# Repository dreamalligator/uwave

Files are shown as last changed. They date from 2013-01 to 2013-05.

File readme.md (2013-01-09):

uwave
#uWave Theremin
One of three devices made for EECS Senior Design at UCF, Fall 2012. See http://www.eecs.ucf.edu/seniordesign/su2012fa2012/g01.

##Related 

* [SenseBox](https://github.com/antivapor/sensebox)
* [Expandome](https://github.com/antivapor/expandome)
* [EMI-Browser](https://github.com/antivapor/emi-browser)

##License
This work is licensed under a [Creative Commons Attribution-ShareAlike 3.0 Unported License](http://creativecommons.org/licenses/by-sa/3.0/).

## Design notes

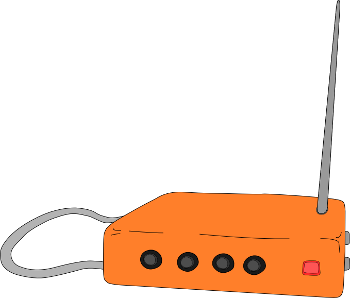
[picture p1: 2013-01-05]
uwave.png

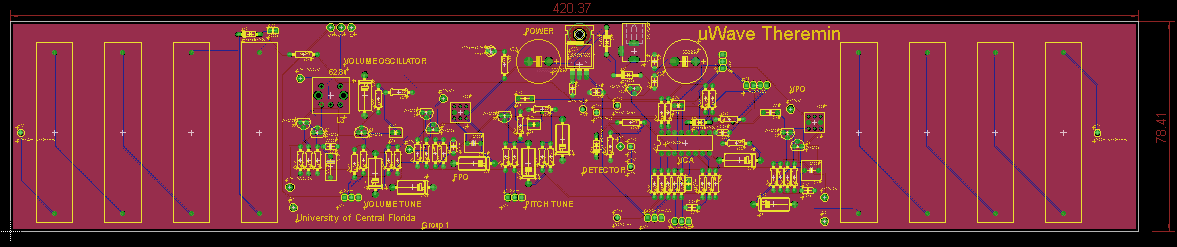
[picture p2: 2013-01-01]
pcb.png

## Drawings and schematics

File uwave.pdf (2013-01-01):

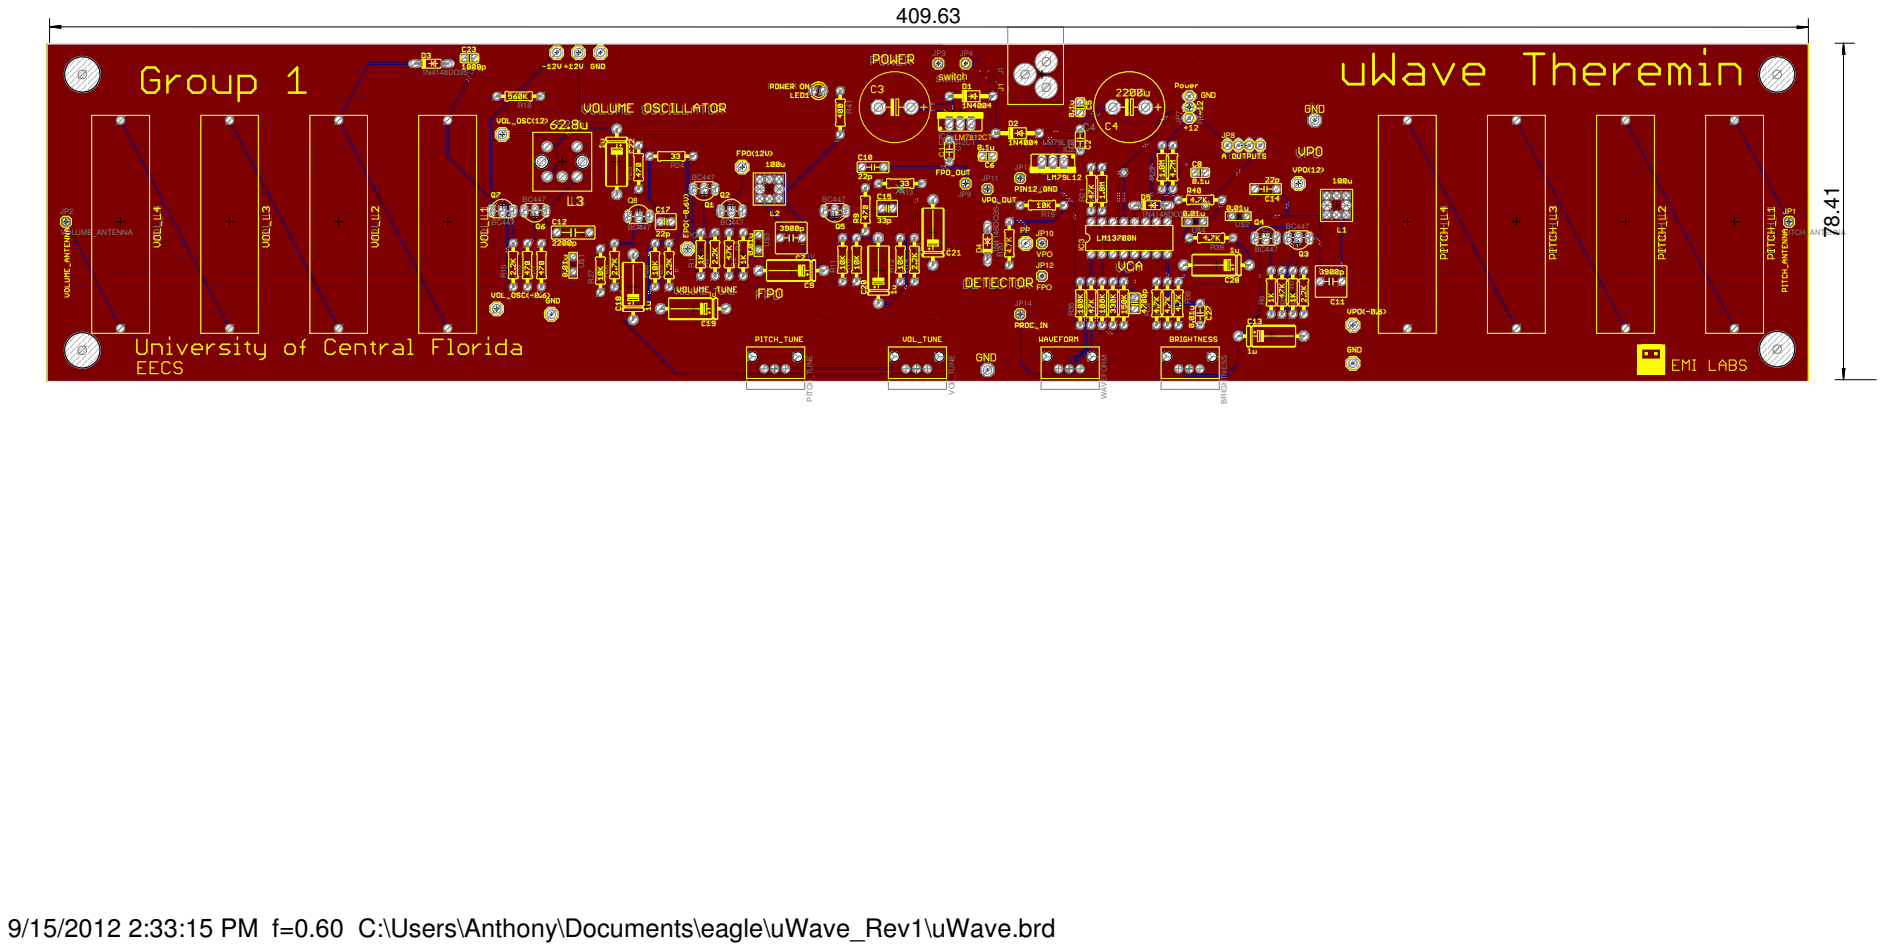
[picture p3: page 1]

9/15/2012 2:33:15 PM f=0.60 C:\Users\Anthony\Documents\eagle\uWave_Rev1\uWave.brd

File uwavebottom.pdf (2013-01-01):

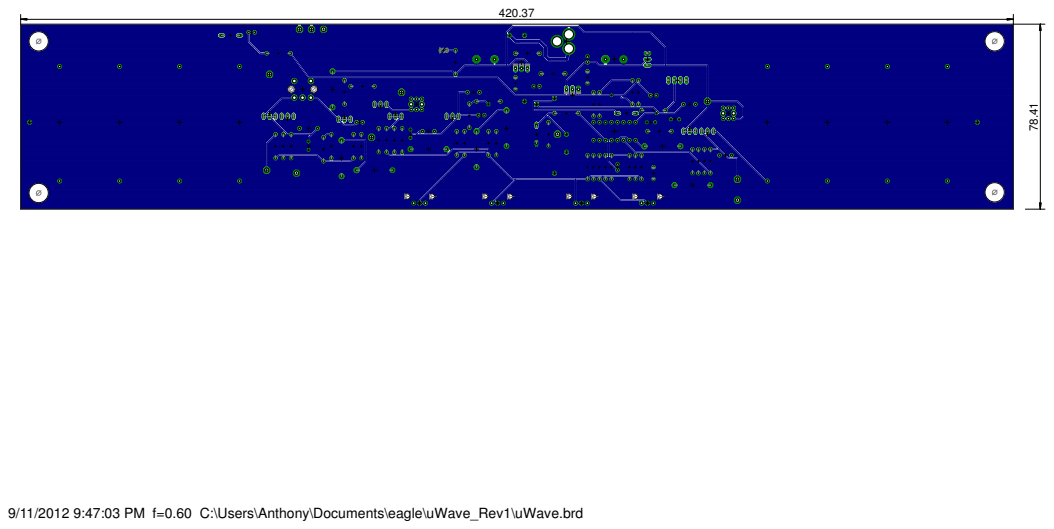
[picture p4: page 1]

9/11/2012 9:47:03 PM f=0.60 C:\Users\Anthony\Documents\eagle\uWave_Rev1\uWave.brd

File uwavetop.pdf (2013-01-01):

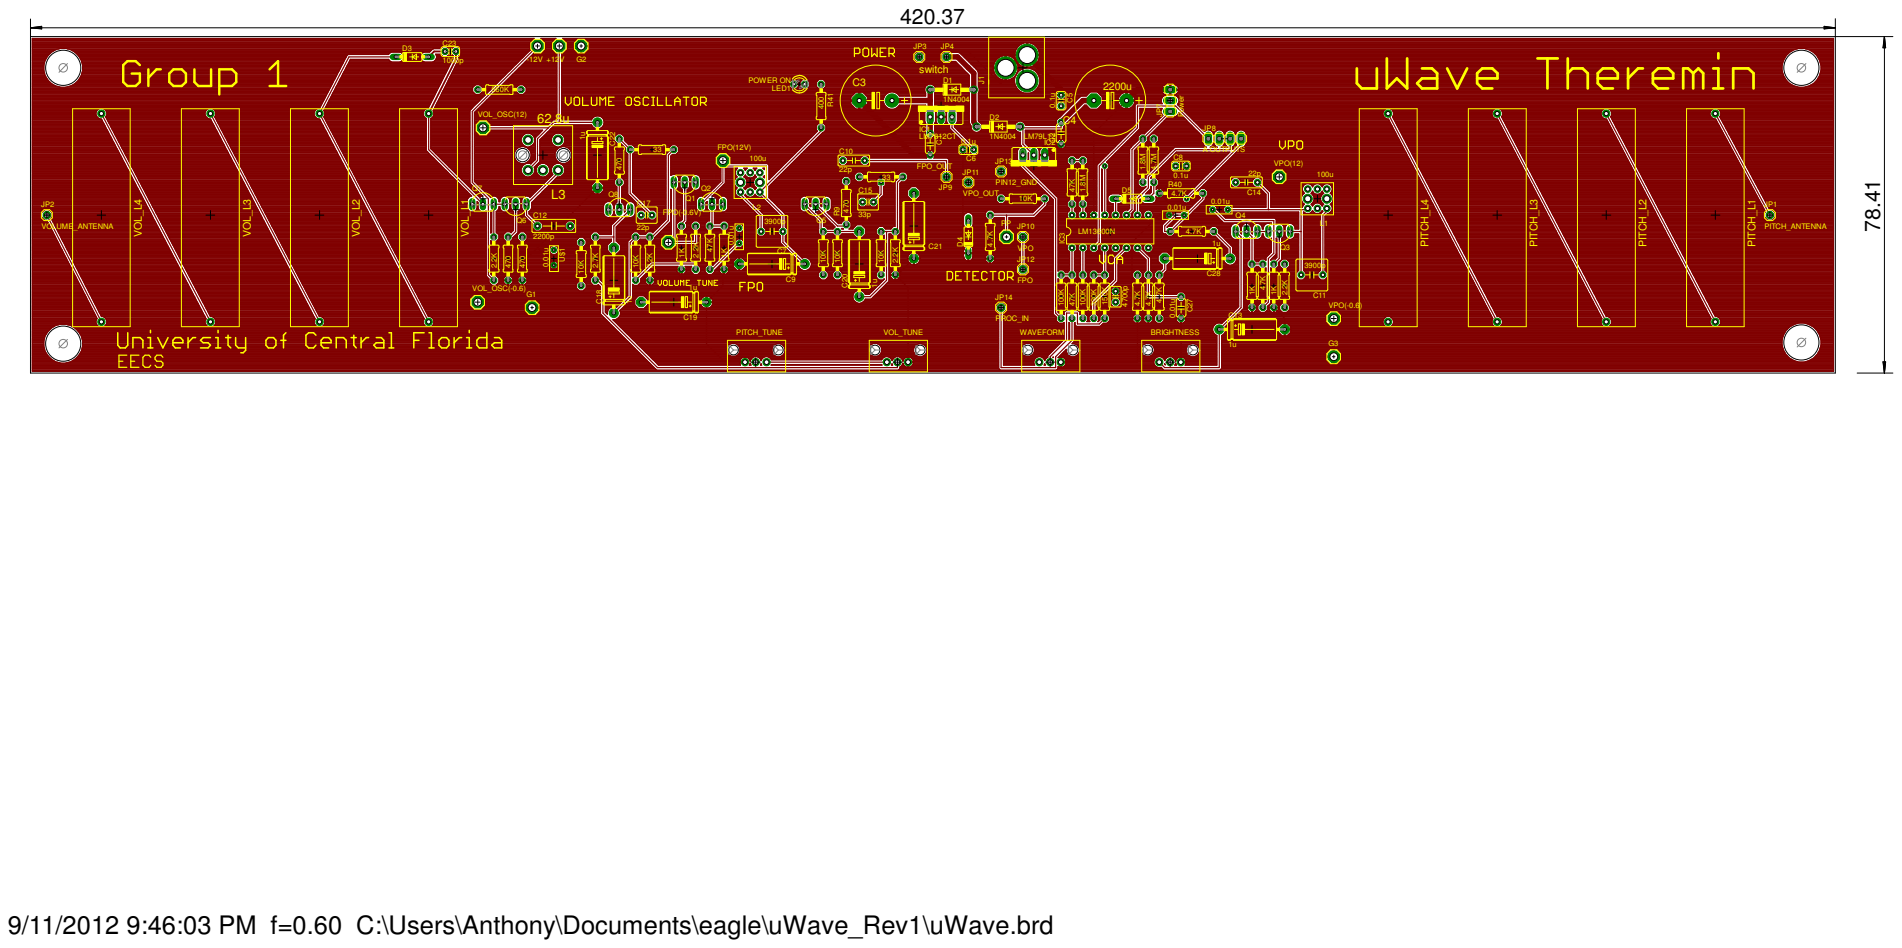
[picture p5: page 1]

9/11/2012 9:46:03 PM f=0.60 C:\Users\Anthony\Documents\eagle\uWave_Rev1\uWave.brd

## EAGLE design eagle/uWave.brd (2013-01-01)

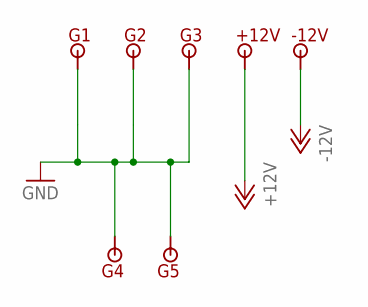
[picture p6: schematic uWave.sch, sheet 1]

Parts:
+12V: TEST1X1; TP1X1
-12V: TEST1X1; TP1X1
G1, G2, G3, G4, G5: TEST1X1; TP1X1

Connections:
+12V: +12V.P$1; also elsewhere on the board
-12V: -12V.P$1; also elsewhere on the board
GND: G1.P$1, G2.P$1, G3.P$1, G4.P$1, G5.P$1; also elsewhere on the board

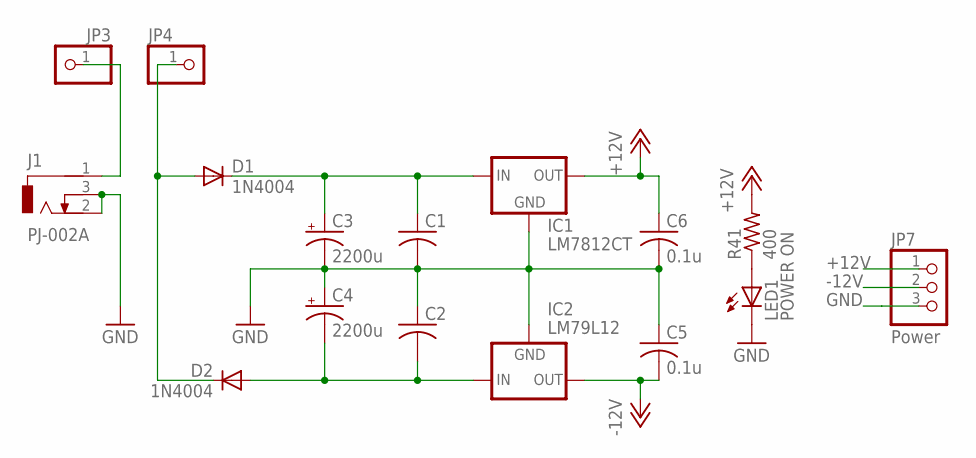
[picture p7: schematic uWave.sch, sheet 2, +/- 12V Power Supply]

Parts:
C1, C2: C-US050-024X044; C050-024X044
C3, C4: 2200u; E7,5-16
C5, C6: 0.1u; C025-024X044
D1, D2: 1N4004; DO41-10
IC1: LM7812CT; 78XXS
IC2: LM79L12; 79XXS
J1: PJ-002A
JP3, JP4: PINHD-1X1; 1X01
JP7: Power; 1X03
LED1: POWER ON; LED3MM
R41: 400; 0207/10

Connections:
+12V: C6.1, IC1.OUT, JP7.1, R41.2; also elsewhere on the board
-12V: C5.2, IC2.OUT, JP7.2; also elsewhere on the board
GND: C1.2, C2.1, C3.-, C4.+, C5.1, C6.2, IC1.GND, IC2.GND, J1.2, J1.3, JP7.3, LED1.K (C); also elsewhere on the board
unnamed: C1.1, C3.+, D1.C, IC1.IN
unnamed: C2.2, C4.-, D2.A, IC2.IN
unnamed: LED1.A, R41.1
unnamed: D1.A, D2.C, JP4.1
unnamed: J1.1, JP3.1

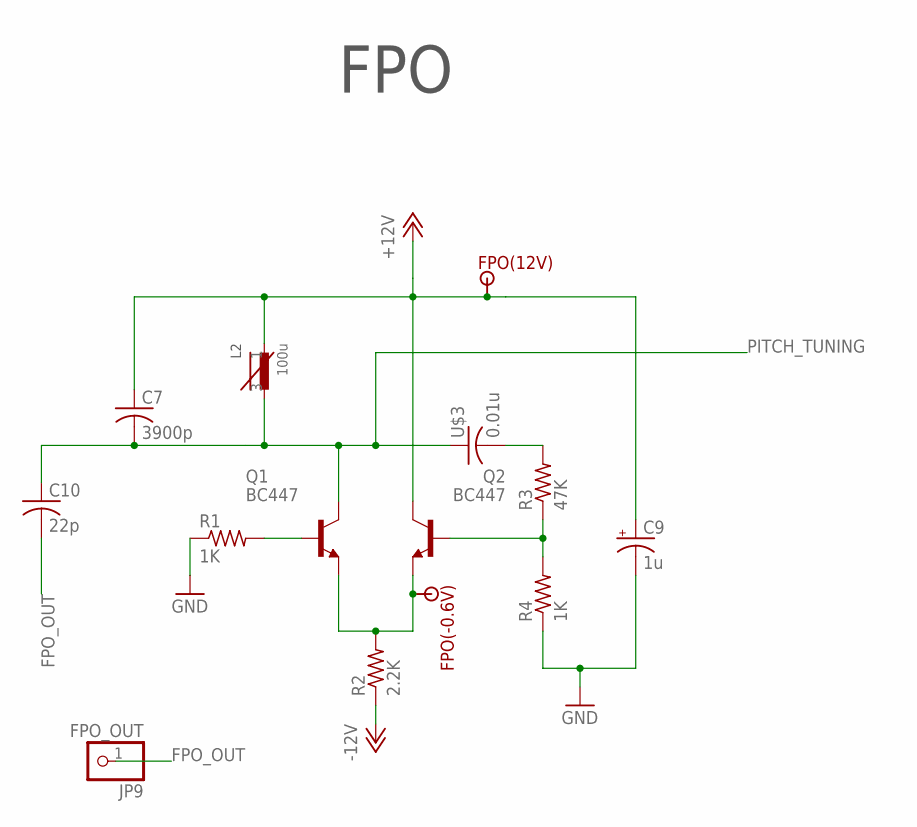
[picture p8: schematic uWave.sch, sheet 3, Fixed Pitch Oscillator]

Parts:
C7: 3900p; C050-075X075
C9: 1u; E15-5
C10: 22p; C050-025X075
FPO(12V): TEST1X1; TP1X1
FPO(-0.6V): TEST1X1; TP1X1
JP9: FPO_OUT; 1X01
L2: 100u; T1040Z
Q1, Q2: BC447; TO92-EBC
R1, R4: 1K; 0207/10
R2: 2.2K; 0207/10
R3: 47K; 0207/10
U$3: 0.01u; QXY

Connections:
+12V: C7.1, C9.+, FPO(12V).P$1, L2.1, Q2.C; also elsewhere on the board
-12V: R2.1; also elsewhere on the board
FPO_OUT: C10.2, JP9.1
GND: C9.-, R1.1, R4.1; also elsewhere on the board
unnamed: Q1.B, R1.2
unnamed: Q2.B, R3.1, R4.2
unnamed: FPO(-0.6V).P$1, Q1.E, Q2.E, R2.2
unnamed: R3.2, U$3.P$2 (2)
PITCH_TUNING: C7.2, C10.1, L2.3, Q1.C, U$3.P$1 (1); also elsewhere on the board

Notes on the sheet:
FPO

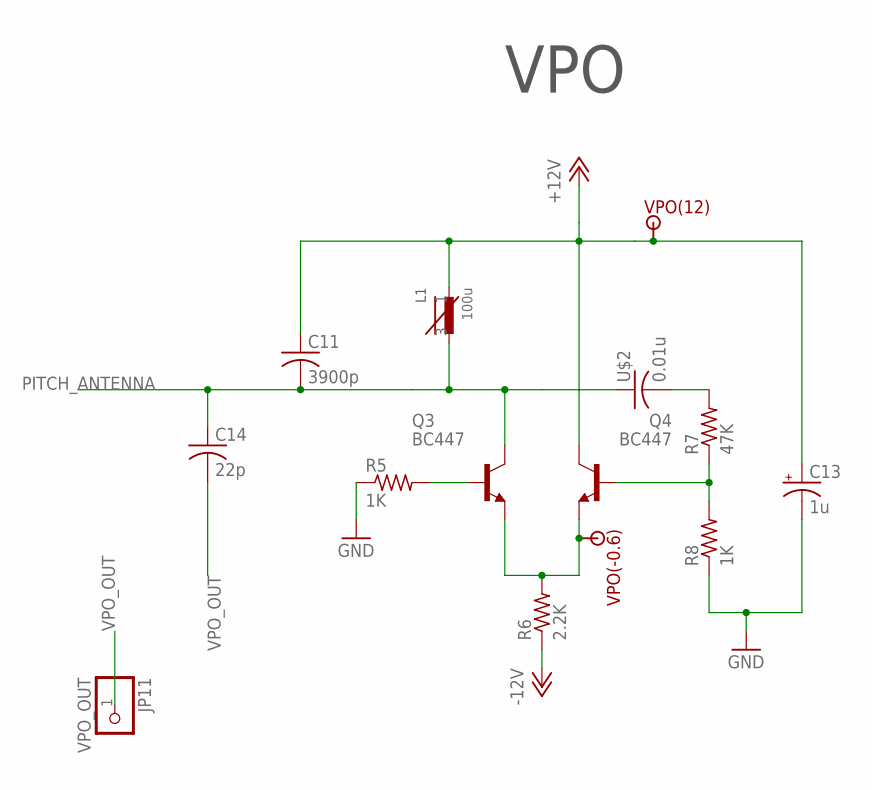
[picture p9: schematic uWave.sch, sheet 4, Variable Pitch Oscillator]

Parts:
C11: 3900p; C050-075X075
C13: 1u; E15-5
C14: 22p; C050-025X075
JP11: VPO_OUT; 1X01
L1: 100u; T1040Z
Q3, Q4: BC447; TO92-EBC
R5, R8: 1K; 0207/10
R6: 2.2K; 0207/10
R7: 47K; 0207/10
U$2: 0.01u; QXY
VPO(12): TEST1X1; TP1X1
VPO(-0.6): TEST1X1; TP1X1

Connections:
+12V: C11.1, C13.+, L1.1, Q4.C, VPO(12).P$1; also elsewhere on the board
-12V: R6.1; also elsewhere on the board
GND: C13.-, R5.1, R8.1; also elsewhere on the board
unnamed: Q3.B, R5.2
unnamed: Q4.B, R7.1, R8.2
unnamed: Q3.E, Q4.E, R6.2, VPO(-0.6).P$1
unnamed: R7.2, U$2.P$2 (2)
PITCH_ANTENNA: C11.2, C14.1, L1.3, Q3.C, U$2.P$1 (1); also elsewhere on the board
VPO_OUT: C14.2, JP11.1

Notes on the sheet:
VPO

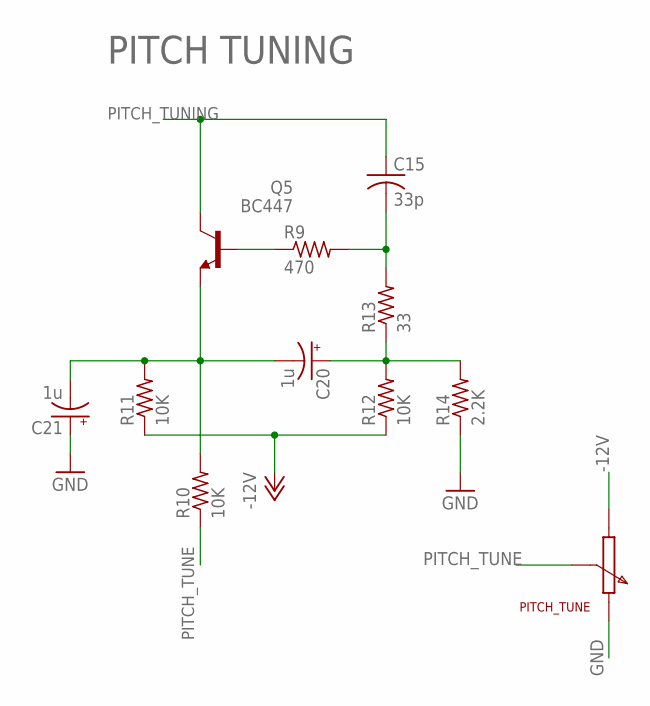
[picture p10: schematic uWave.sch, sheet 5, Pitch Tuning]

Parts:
C15: 33p; C025-040X050
C20, C21: 1u; E15-5
PITCH_TUNE: POT; EVUE
Q5: BC447; TO92-EBC
R9: 470; 0207/10
R10, R11, R12: 10K; 0207/10
R13: 33; 0207/10
R14: 2.2K; 0207/10

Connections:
-12V: PITCH_TUNE.3, R11.1, R12.1; also elsewhere on the board
GND: C21.+, PITCH_TUNE.1, R14.1; also elsewhere on the board
unnamed: C15.2, R9.2, R13.2
unnamed: C20.+, R12.2, R13.1, R14.2
unnamed: Q5.B, R9.1
unnamed: C20.-, C21.-, Q5.E, R10.2, R11.2
PITCH_TUNE: PITCH_TUNE.2, R10.1
PITCH_TUNING: C15.1, Q5.C; also elsewhere on the board

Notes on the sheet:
PITCH TUNING

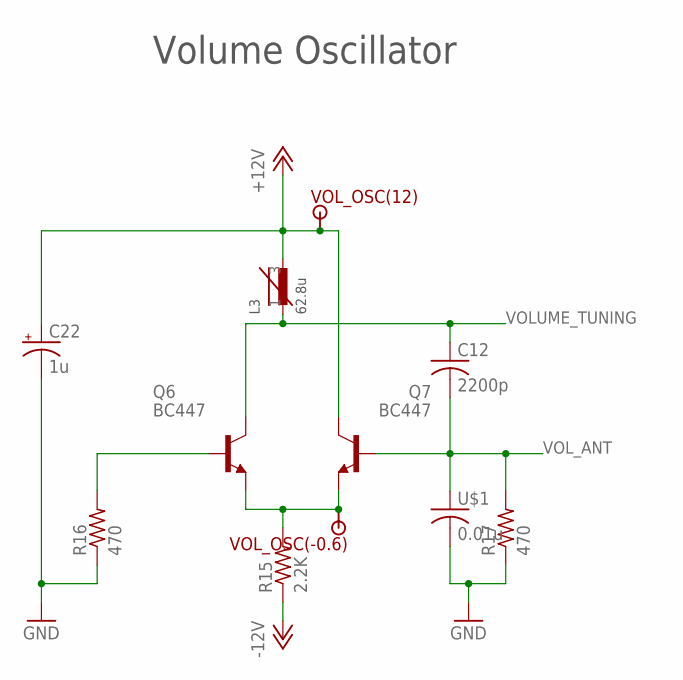
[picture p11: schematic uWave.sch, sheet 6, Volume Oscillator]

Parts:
C12: 2200p; C075-032X103
C22: 1u; E15-5
L3: 62.8u; SLOT-TEN-5-10
Q6, Q7: BC447; TO92-EBC
R15: 2.2K; 0207/10
R16, R17: 470; 0207/10
U$1: 0.01u; QXY
VOL_OSC(12): TEST1X1; TP1X1
VOL_OSC(-0.6): TEST1X1; TP1X1

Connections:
+12V: C22.+, L3.3, Q7.C, VOL_OSC(12).P$1; also elsewhere on the board
-12V: R15.1; also elsewhere on the board
GND: C22.-, R16.1, R17.1, U$1.P$2 (2); also elsewhere on the board
unnamed: Q6.E, Q7.E, R15.2, VOL_OSC(-0.6).P$1
unnamed: Q6.B, R16.2
VOLUME_TUNING: C12.1, L3.1, Q6.C; also elsewhere on the board
VOL_ANT: C12.2, Q7.B, R17.2, U$1.P$1 (1); also elsewhere on the board

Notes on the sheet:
Volume Oscillator

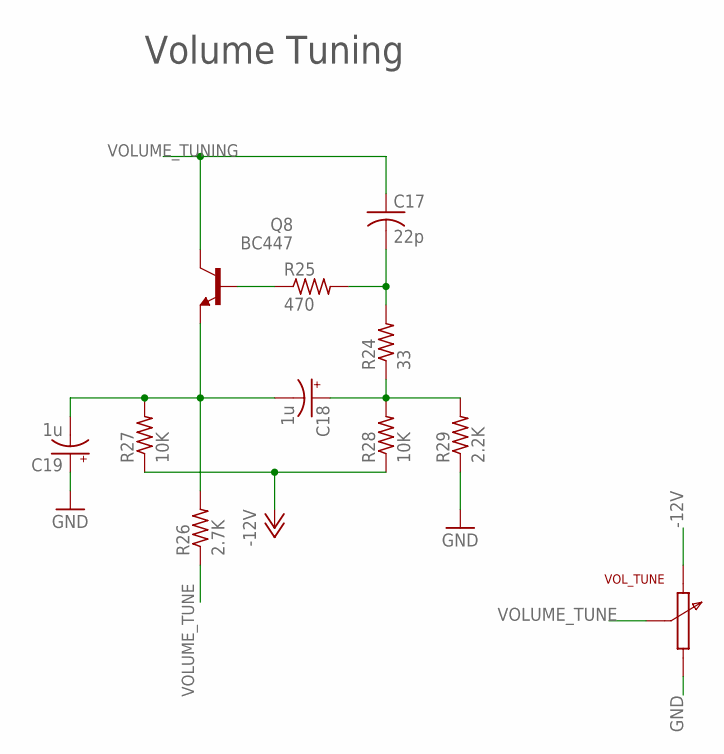
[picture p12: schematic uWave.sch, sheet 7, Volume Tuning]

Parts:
C17: 22p; C025-040X050
C18, C19: 1u; E15-5
Q8: BC447; TO92-EBC
R24: 33; 0207/10
R25: 470; 0207/10
R26: 2.7K; 0207/10
R27, R28: 10K; 0207/10
R29: 2.2K; 0207/10
VOL_TUNE: POT; EVUE

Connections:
-12V: R27.1, R28.1, VOL_TUNE.1; also elsewhere on the board
GND: C19.+, R29.1, VOL_TUNE.3; also elsewhere on the board
unnamed: C17.2, R24.2, R25.2
unnamed: C18.+, R24.1, R28.2, R29.2
unnamed: Q8.B, R25.1
unnamed: C18.-, C19.-, Q8.E, R26.2, R27.2
VOLUME_TUNE: R26.1, VOL_TUNE.2
VOLUME_TUNING: C17.1, Q8.C; also elsewhere on the board

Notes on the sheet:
Volume Tuning

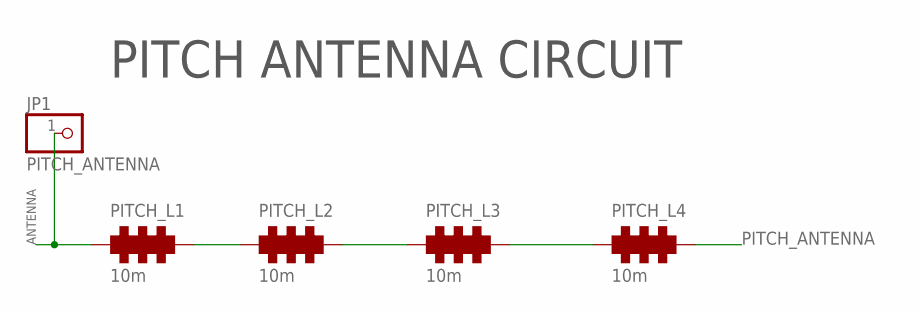
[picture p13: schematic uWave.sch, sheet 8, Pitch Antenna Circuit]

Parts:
JP1: PITCH_ANTENNA; 1X01
PITCH_L1, PITCH_L2, PITCH_L3, PITCH_L4: 10m; INDUCTOR_CHOKE

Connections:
ANTENNA: JP1.1, PITCH_L1.P$1
unnamed: PITCH_L1.P$2, PITCH_L2.P$1
unnamed: PITCH_L2.P$2, PITCH_L3.P$1
unnamed: PITCH_L3.P$2, PITCH_L4.P$1
PITCH_ANTENNA: PITCH_L4.P$2; also elsewhere on the board

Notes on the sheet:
PITCH ANTENNA CIRCUIT

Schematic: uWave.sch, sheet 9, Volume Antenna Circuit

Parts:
C23: 1000p; C025-024X044
D3: 1N4148DO35-7; DO35-7
JP2: VOLUME_ANTENNA; 1X01
R18: 560K; 0207/10
VOL_L1, VOL_L2, VOL_L3, VOL_L4: 2.5m; INDUCTOR_CHOKE

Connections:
unnamed: VOL_L2.P$2, VOL_L3.P$1
unnamed: VOL_L3.P$2, VOL_L4.P$1
unnamed: C23.1, D3.A, R18.2
unnamed: D3.C, VOL_L1.P$2, VOL_L2.P$1
VCA_PROC: R18.1; also elsewhere on the board
VOLUME_ANTENNA: JP2.1, VOL_L4.P$2
VOL_ANT: C23.2, VOL_L1.P$1; also elsewhere on the board

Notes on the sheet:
VOLUME ANTENNA CIRCUIT

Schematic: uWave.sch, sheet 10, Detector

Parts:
C25: 4700p; C025-025X050
D4: 1N4148DO35-7; DO35-7
JP10: VPO; 1X01
JP12: FPO; 1X01
PP: TEST1X1; TP1X1
R19: 10K; 0207/10
R20: 4.7K; 0207/10

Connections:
FPO_VPO: D4.A, JP10.1, JP12.1, R19.2
GND: C25.2, D4.C, R20.1; also elsewhere on the board
PITCH_PREVIEW: C25.1, PP.P$1, R19.1, R20.2; also elsewhere on the board

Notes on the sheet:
DETECTOR

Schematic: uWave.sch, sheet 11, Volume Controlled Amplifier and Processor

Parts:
BRIGHTNESS: POT; EVUE
C8: 0.1u; C025-024X044
C27: 0.01u; C050-024X044
C28: 1u; E15-5
D5: 1N4148DO35-7; DO35-7
IC3: LM13600N; DIL16
JP8: A OUTPUTS; 1X04
JP13: PIN12_GND; 1X01
JP14: PROC_IN; 1X01
R21, R36: 47K; 0207/10
R22, R23: 1.8M; 0207/10
R30: 4.7M; 0207/10
R31: 150K; 0207/10
R32: 330K; 0207/10
R33, R35: 100K; 0207/10
R34, R37, R38, R39, R40: 4.7K; 0207/10
U$4: 0.01u; QXY
WAVEFORM: POT; EVUE

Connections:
+12V: BRIGHTNESS.1, IC3.11 (V+), R21.2, R22.2, R23.2; also elsewhere on the board
-12V: IC3.6 (V-), R32.1, R35.1, R38.2, WAVEFORM.1; also elsewhere on the board
AMP_IN: IC3.10 (BUFF/IN), JP8.3
AMP_OUT: IC3.9 (BUFF/OUT), JP8.4
AUDIO_OUT: JP8.2, R39.2, R40.2, U$4.P$1 (1)
BRIGHTNESS: BRIGHTNESS.2, R33.1
GND: BRIGHTNESS.3, C8.2, C27.2, IC3.14 (+IN), R34.1, R37.1, R40.1, U$4.P$2 (2), WAVEFORM.3; also elsewhere on the board
unnamed: IC3.15 (DIODE/BIAS), R23.1
unnamed: C28.+, R39.1
unnamed: IC3.16 (AMP/BIAS), R21.1
unnamed: IC3.2 (DIODE/BIAS), R33.2
unnamed: D5.A, R30.1
unnamed: IC3.4 (-IN), R31.1, R32.2, R34.2
unnamed: IC3.1 (AMP/BIAS), R35.2, R36.2
unnamed: C28.-, IC3.8 (BUFF/OUT), R38.1
unnamed: D5.C, IC3.12 (OUT), JP13.1
unnamed: C27.1, IC3.5 (OUT), IC3.7 (BUFF/IN), R37.2
unnamed: JP14.1, R36.1
PITCH_PREVIEW: IC3.3 (+IN), JP8.1; also elsewhere on the board
VCA_PROC: C8.1, IC3.13 (-IN), R22.1, R30.2; also elsewhere on the board
WAVEFORM: R31.2, WAVEFORM.2

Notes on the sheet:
VCA
VCA PROCESSOR

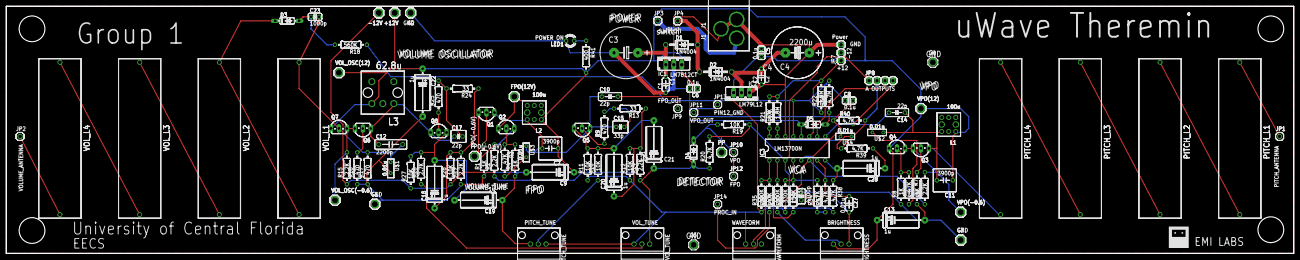
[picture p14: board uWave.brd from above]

Board: 2 copper layers, 410.2 x 78.7 mm, 129 parts (1 on the bottom side), 62 nets.

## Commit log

2013-01-01 eagle files
    [uWave.brd, uWave.sch]
2013-05-22 kicad test.
    [uwave.brd]
